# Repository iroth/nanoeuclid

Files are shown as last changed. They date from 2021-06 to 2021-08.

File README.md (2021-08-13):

# **Neno Euclid**
## _Arduino-based Euclid Rhythm Sequencer_

## **Features**

This sequencer is inspired by Euclidean Circles v2 by vpme.de.

- 4 Channels with 4 gate outputs
- Each channel has 16 steps pattern
- NeoPixels ring is used as main UI elelemt
- Rotary encoder to control various parameters of the pattern
    - Pattern length 1-16 notes
    - Number of "ON" slots in the pattern
    - Pattern start offset
- Each channel can be independently edited, and the 4 channels combination is a "patch"
- You can save and later load up to 16 patches in EEPROM (kept even with power off)
- The unit has internal clock with controlled rythm, but can also be switched to use external eurorack clock signal

### **To build the software**
The following library is needed:
Adafruit_NeoPixel for the NeoPixels ring display [Available on their Github page](https://github.com/adafruit/Adafruit_NeoPixel)

### **Hardware**
This is the circuit diagram (breadboard version). The Fritzing file is included in the Hardware folder.

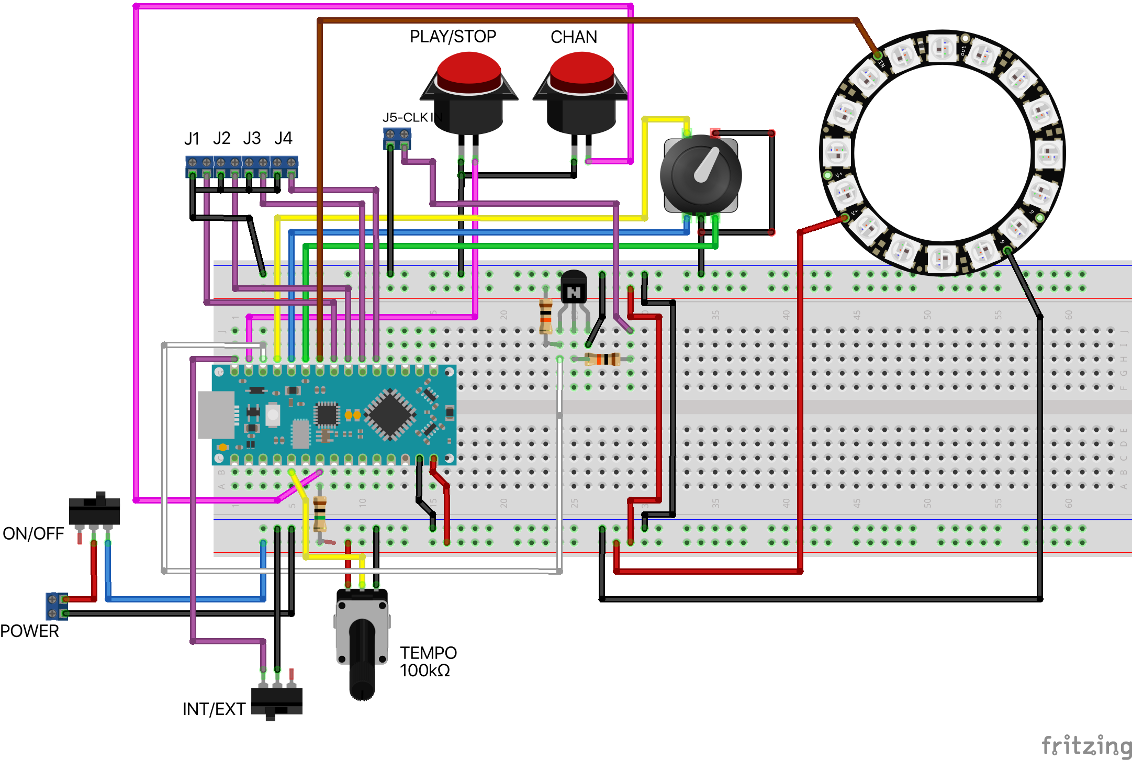
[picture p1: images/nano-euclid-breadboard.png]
circuit Circuit Breadboard


### **User Manual**

OK, not a full manual, but a start on how to use the NanoEuclid module.

Clicking the Channel button switches the current edited channel, the led ring will show the pattern length using the channel color (TBD).

Turning the rotary encoder will shorten or lengthen the pattern length.

Click the rotary encoder once to edit the number of active beats, the number of active beats will be indicated by the bright leds scattered around the pattern. Turning the rotary encoder will increase or decrease the number of active beats.

Click the rotary encoder once more to edit the pattern start position, turning the rotary encoder will shift the starting point forward or backward in the pattern.

Click the Play/Stop button to start playing the sequence. If the switch is in internal mode, the internal clock will be used. If the switch is in EXT mode, the external clock will be used to advance the sequence to the next step in the pattern.

In INT mode, the clock rate is controlled with the Rate potentiometer.

If you like the patch you created (a patch is the combination of patterns in all four channels), you can store it to EEPROM. There are 16 memory slots to save patches to.

To store or load a patch, you need to switch the module to MEMORY mode by long pressing the rotary encoder. Once in MEMORY mode, the led ring will show taken positions in GREEN, free positions in RED, and the current position in pink.

Press the CHN/Store button to store the current patch to the selected memory position.

Press the PLAY/Load button to load the content of memory in the current position to the active patch area.

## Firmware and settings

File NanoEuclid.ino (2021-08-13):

//---------------------------------------------------------
//--------------- NanoEuclid ------------------------------
//---------------------------------------------------------
//
// Euclidean Rythm Sequencer using Arduino Nano Every as
// the processor, a NeoPixels led ring as the main UI
// Rotary Encoder + push button, two buttons a toggle and
// a potentiometer as input devices
//
// The sequencer has 4 channels each with up to 16 steps
// 4 Eurorack Gate outputs are provided
// The sequencer has internal clock, but can be switched to
// use an external clock from Eurorack
//
//---------------------------------------------------------

//---------------------------------------------------------
//
// File: NanoEuclid.ino
// This is the main file of the sequencer
//
// Author: Israel Roth
// Date: May 28, 2021
//
//---------------------------------------------------------

//--------------- Actual Seq Params --------------------
int pattern_len = 16;
int active_beats = 1;
int cur_memory_pos = 0;


//--------------- Sequencer Stuff --------------------

bool isPlaying = false;

#define NUM_CHANNELS 4
int curChannel = 0;
byte euclid_pattern[NUM_CHANNELS][16];
int pattern_length[NUM_CHANNELS] = {16, 16, 16, 16};
int pattern_nactive[NUM_CHANNELS] = {1, 1, 1, 1};
int pattern_offset[NUM_CHANNELS] = {0, 0, 0, 0};
byte gSeqNoteIndex[NUM_CHANNELS] = {0, 0, 0, 0};
int channelGatePin[NUM_CHANNELS] = {2, 3, 4, 5};

int clock_source;
#define CLK_SRC_INT      0
#define CLK_SRC_EXT      1

int curBPM = 120;
unsigned int gSeqT16 = 125;
unsigned long gSeqTimeCurrent;
unsigned long gSeqTimeLast;
unsigned long gSeqTimeGate;

#define PIN_SYNC_IN 10  // clock in pin

bool gSyncOn; // we are in note on phase
bool gSyncOff; // we are in note off phase (after gate)
bool gSyncNoteOn; // trigger note on handling
bool gSyncNoteOff; // trigger note off handling

int edit_mode = 0;
#define EDIT_MODE_PATTERN_LEN      0
#define EDIT_MODE_ACTIVE_BEATS     1
#define EDIT_MODE_OFFSET           2
#define EDIT_MODE_MEMORY           3

void setTempo(void) {
  gSeqT16 = 1000 / ((curBPM * 4) / ((float)60));
  gSeqTimeGate = gSeqT16 / 2;
}

//--------------- The Euclid Thingy --------------------
void offset_pattern(int chan, int offset) {
  if (offset == 0) {
    return;
  }
  int abs_off = abs(offset);
  int pLen = pattern_length[chan];

  for (int i = 0 ; i < abs_off ; i++) {
    if (offset < 0) {
      int keep = euclid_pattern[chan][0];
      for (int j = 0 ; j < pLen-1 ; j++) {
        euclid_pattern[chan][j] = euclid_pattern[chan][j+1] ;
      }
      euclid_pattern[chan][pLen-1] = keep;
    }
    else {
      int keep = euclid_pattern[chan][pLen-1];
      for (int j = pLen-1 ; j > 0 ; j--) {
        euclid_pattern[chan][j] = euclid_pattern[chan][j-1];
      }
      euclid_pattern[chan][0] = keep;
    }
  }
}

int euclid(int n, int k, int chan, int offset) {
    int spaces = n - k;
    float per_pulse = (float) n / (float) k;
    float per_space = (float) n / (float) spaces;
    int i;
    float pos = 0.0f;

    Serial.print("Euclid for: "); Serial.print(n); Serial.print(" / "); Serial.print(k); Serial.println();
    Serial.print("Per Pulse: "); Serial.print(per_pulse); Serial.println();
    Serial.print("Per Space: "); Serial.print(per_space); Serial.println();
 
    if (per_space > per_pulse) {
        for (i = 0 ; i < n ; i++) {     // empty array to 1
            euclid_pattern[chan][i] = 1;
        }
        for (i = 0 ; i < spaces ; i++) {
            int p = (int) pos;
            euclid_pattern[chan][p] = 0;
            pos = pos + per_space;
        }
    }
    else {
        for (i = 0 ; i < n ; i++) {     // empty array
            euclid_pattern[chan][i] = 0;
        }
        for (i = 0 ; i < k ; i++) {
          int p = (int) pos;
          euclid_pattern[chan][p] = 1;
          pos = pos + per_pulse;
        }
    }
    offset_pattern(chan, offset);
}

// the setup function runs once when you press reset or power the board
void setup() {

  Serial.begin(115200);

  euclid(16,1,0,0); // init euclid patterns for all channels
  euclid(16,2,1,0);
  euclid(16,4,2,0);
  euclid(16,8,3,0);

  gSeqTimeCurrent = millis();
  gSyncOn = false;
  gSyncOff = true;
  gSyncNoteOn = false;
  gSyncNoteOff = false;
  gSeqTimeLast = gSeqTimeCurrent - gSeqT16;
  for (int i = 0 ; i < NUM_CHANNELS; i++) {   // Gate output pins
    pinMode(channelGatePin[i], OUTPUT);
  }
  pinMode(PIN_SYNC_IN, INPUT_PULLUP);         // ext. clock pin

  RotaryEncoderSetup();
  RingDisplaySetup();
  PushButtonsSetup();
  TempoPotSetup();
  ClockToggleSetup();
  PatchStorageSetup();

}

// the loop function runs over and over again forever
void loop() {
  handleRotaryEncoder();
  handlePushButtons();
  handleTempoPot();
  handleClockToggle();
  displayLedRing();

  gSeqTimeCurrent = millis();

    if (clock_source == CLK_SRC_EXT) {

      // external clock

      // sync received for note on?
      if (digitalRead(PIN_SYNC_IN) == LOW) {
        if (!gSyncOn) {
          gSyncOn = true; // first part of sync pulse detected
          gSyncOff = false;
          gSyncNoteOn = true;
        }
      } else {
        if (!gSyncOff) {
          gSyncOn = false; // pulse ended
          gSyncOff = true;
          gSyncNoteOff = true;
        }
      }

    } else {

      // internal clock

      // time for note on?
      if (gSeqTimeCurrent - gSeqTimeLast >= gSeqT16)
      {
        if (!gSyncOn) {
          gSyncOn = true;
          gSyncOff = false;
          gSyncNoteOn = true;
        }
        gSeqTimeLast = gSeqTimeLast + gSeqT16; // update time for next note
      }

      // time for note off?
      if (gSeqTimeCurrent - gSeqTimeLast >= gSeqTimeGate)
      {
        if (!gSyncOff) {
          gSyncOn = false;
          gSyncOff = true;
          gSyncNoteOff = true;
        }
      }

    } // if (clock_source == SYNC_EXT)
  

  if (gSyncNoteOn) {
    gSyncNoteOn = false;
    for (int i = 0 ; i < NUM_CHANNELS; i++) {
      gSeqNoteIndex[i]++;
      if (gSeqNoteIndex[i] >= pattern_length[i]) {
        gSeqNoteIndex[i] = 0;
      }
      if (euclid_pattern[i][gSeqNoteIndex[i]]) {
        if (isPlaying) {
          digitalWrite(channelGatePin[i], HIGH);
        }
      }
      displayLedRing();
    }
  }

  // time for note off?
  if (gSyncNoteOff)
  {
     gSyncNoteOff = false;
     for (int i = 0 ; i < NUM_CHANNELS; i++) {
      if (isPlaying) {
        digitalWrite(channelGatePin[i], LOW);
      }        
     }
 }

}

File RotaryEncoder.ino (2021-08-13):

//---------------------------------------------------------
//--------------- EuclidNamo ------------------------------
//---------------------------------------------------------
//
// Euclidean Rythm Sequencer using Arduino Nano Every as
// the processor, a NeoPixels led ring as the main UI
// Rotary Encoder + push button, two buttons a toggle and
// a potentiometer as input devices
//
// The sequencer has 4 channels each with up to 16 steps
// 4 Eurorack Gate outputs are provided
// The sequencer has internal clock, but can be switch to
// use an external clock from Eurorack
//
//---------------------------------------------------------

//---------------------------------------------------------
//
// File: RotaryEncoder.ino
// Functions to handle the rotary encoder + push button
//
// Author: Israel Roth
// Date: May 28, 2021
//
//---------------------------------------------------------

//--------------- Rotary Encoder Stuff --------------------
#define PIN_ENCODER_A      7
#define PIN_ENCODER_B      8
#define PIN_ENCODER_SWITCH 9
#define LONG_PRESS_TIME    800
static uint8_t enc_prev_pos   = 0;
static uint8_t enc_flags      = 0;
int lastState = LOW;
int currentState;
unsigned long pressedTime  = 0;
bool isPressing = false;
bool isLongDetected = false;

void RotaryEncoderSetup() {
  pinMode(PIN_ENCODER_A, INPUT_PULLUP);
  pinMode(PIN_ENCODER_B, INPUT_PULLUP);
  pinMode(PIN_ENCODER_SWITCH, INPUT_PULLUP);
  // get an initial reading on the encoder pins
  if (digitalRead(PIN_ENCODER_A) == LOW) {
    enc_prev_pos |= (1 << 0);
  }
  if (digitalRead(PIN_ENCODER_B) == LOW) {
    enc_prev_pos |= (1 << 1);
  }
}

void handleShortButtonPress() {
  Serial.println("Short Button Pressed");
  edit_mode++;
  if (edit_mode > EDIT_MODE_OFFSET) {
    edit_mode = EDIT_MODE_PATTERN_LEN;
  }
}

void handleLongButtonPress() {
  Serial.println("Long Button Pressed");
  edit_mode = EDIT_MODE_MEMORY;
  dumpEEPROM();
}

void handleRotaryInc() {
  Serial.println("Rotary Inc");
  bool anyChange = false;
  switch(edit_mode) {
    case EDIT_MODE_PATTERN_LEN:
      if (pattern_length[curChannel] > 1) {
        pattern_length[curChannel]--;
        if (pattern_nactive[curChannel] > pattern_length[curChannel]) {
          pattern_nactive[curChannel] = pattern_length[curChannel];
        }
        if (pattern_offset[curChannel] > pattern_length[curChannel]-1) {
          pattern_nactive[curChannel] = 0;
        }
        anyChange = true;        
      }
      break;      
    case EDIT_MODE_ACTIVE_BEATS:
      if(pattern_nactive[curChannel] < pattern_length[curChannel]) {
        pattern_nactive[curChannel]++;
        anyChange = true;
      }
      break;      
    case EDIT_MODE_OFFSET:
      pattern_offset[curChannel]--;
      if (pattern_offset[curChannel] < 0) {
        pattern_offset[curChannel] = pattern_length[curChannel] - 1;
      }
      anyChange = true;       
      break;
    case EDIT_MODE_MEMORY:
      if (cur_memory_pos > 0) {
        cur_memory_pos--;
      }
      else {
        cur_memory_pos = 15;
      }
      break;      
  }
  if (anyChange) {
    euclid(pattern_length[curChannel], pattern_nactive[curChannel], curChannel, pattern_offset[curChannel]);
  }
}

void handleRotaryDec() {
  Serial.println("Rotary Dec");
  bool anyChange = false;
  switch(edit_mode) {
    case EDIT_MODE_PATTERN_LEN:
      if (pattern_length[curChannel] < 16) {
        pattern_length[curChannel]++; 
        anyChange = true;       
      }
      break;      
    case EDIT_MODE_ACTIVE_BEATS:
      if(pattern_nactive[curChannel] > 0) {
        pattern_nactive[curChannel]--;
        anyChange = true;
      }
      break;      
    case EDIT_MODE_OFFSET:
      pattern_offset[curChannel]++; 
      if (pattern_offset[curChannel] >= (pattern_length[curChannel])) {
        pattern_offset[curChannel] = 0;        
      }
      anyChange = true;        
      break;      
    case EDIT_MODE_MEMORY:
      if (cur_memory_pos < 15) {
        cur_memory_pos++;
      }
      else {
        cur_memory_pos = 0;
      }
      break;      
  }
  if (anyChange) {
    euclid(pattern_length[curChannel], pattern_nactive[curChannel], curChannel, pattern_offset[curChannel]);
  }
}

void handleRotaryEncoder() {
  int8_t enc_action = 0; // 1 or -1 if moved, sign is direction
  uint8_t enc_cur_pos = 0;
  // read in the encoder state first
  if (digitalRead(PIN_ENCODER_A) == LOW) {
    enc_cur_pos |= (1 << 0);
  }
  if (digitalRead(PIN_ENCODER_B) == LOW) {
    enc_cur_pos |= (1 << 1);
  }

  // if any rotation at all
  if (enc_cur_pos != enc_prev_pos)
  {
    if (enc_prev_pos == 0x00)
    {
      // this is the first edge
      if (enc_cur_pos == 0x01) {
        enc_flags |= (1 << 0);
      }
      else if (enc_cur_pos == 0x02) {
        enc_flags |= (1 << 1);
      }
    }

    if (enc_cur_pos == 0x03)
    {
      // this is when the encoder is in the middle of a "step"
      enc_flags |= (1 << 4);
    }
    else if (enc_cur_pos == 0x00)
    {
      // this is the final edge
      if (enc_prev_pos == 0x02) {
        enc_flags |= (1 << 2);
      }
      else if (enc_prev_pos == 0x01) {
        enc_flags |= (1 << 3);
      }

      // check the first and last edge
      // or maybe one edge is missing, if missing then require the middle state
      // this will reject bounces and false movements
      if (bit_is_set(enc_flags, 0) && (bit_is_set(enc_flags, 2) || bit_is_set(enc_flags, 4))) {
        enc_action = 1;
      }
      else if (bit_is_set(enc_flags, 2) && (bit_is_set(enc_flags, 0) || bit_is_set(enc_flags, 4))) {
        enc_action = 1;
      }
      else if (bit_is_set(enc_flags, 1) && (bit_is_set(enc_flags, 3) || bit_is_set(enc_flags, 4))) {
        enc_action = -1;
      }
      else if (bit_is_set(enc_flags, 3) && (bit_is_set(enc_flags, 1) || bit_is_set(enc_flags, 4))) {
        enc_action = -1;
      }

      enc_flags = 0; // reset for next time
    }
  }

  enc_prev_pos = enc_cur_pos;

  if (enc_action > 0) {
    handleRotaryDec();
  }
  else if (enc_action < 0) {
    handleRotaryInc();
  }

  // remember that the switch is active low 
  currentState = digitalRead(PIN_ENCODER_SWITCH);
  if(lastState == HIGH && currentState == LOW) {        // button is pressed
    pressedTime = millis();
    isPressing = true;
    isLongDetected = false;
  } else if(lastState == LOW && currentState == HIGH) { // button is released
    isPressing = false;
    if (!isLongDetected) {
      handleShortButtonPress();      
    }
  }

  if(isPressing == true && isLongDetected == false) {
    long pressDuration = millis() - pressedTime;
    if( pressDuration > LONG_PRESS_TIME ) {
      isLongDetected = true;
      handleLongButtonPress();
    }
  }

  // save the the last state
  lastState = currentState;

}

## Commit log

2021-06-27 added board diagram and fritzing file, and improved readme to include a simple user manual
    [nano-euclid.fzz]
2021-07-11 more uniform disribution in euclid algo some serial debug info started working on eeprom storage, but did not complete allow zero active to mute a channel reduce current consumption of NeoPixels by r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
    [Stripboard.fzz]
2021-08-13 bug fixing and completion of EEPROM store/load functionality
    [NanoEuclid.ino, PatchStorage.ino, PushButtons.ino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]
